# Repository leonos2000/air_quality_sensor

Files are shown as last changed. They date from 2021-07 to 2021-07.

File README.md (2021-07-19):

# Air Quality Sensor

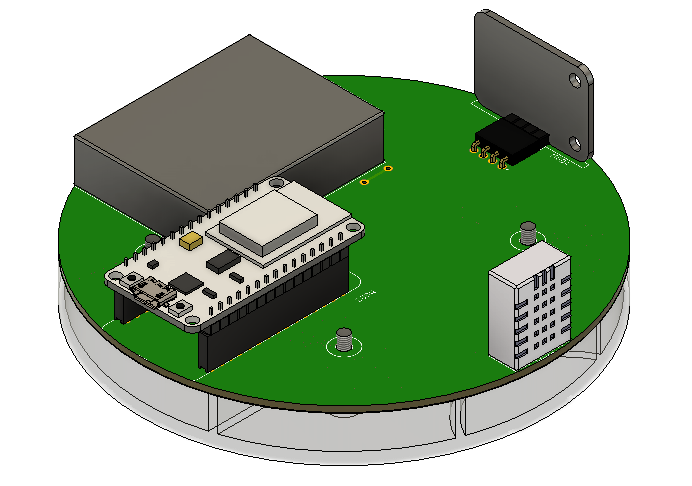
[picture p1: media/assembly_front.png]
3d_assembly

## Overview

This is air quality sensor that can measure PM1.0, PM2.5, PM10, tVOC and eCO2, but also temperature and humidity.

This is second version of my project witch has some improvements for example separators in 3d printed casing that prevent heating DHT22 sensor from nodeMCU.

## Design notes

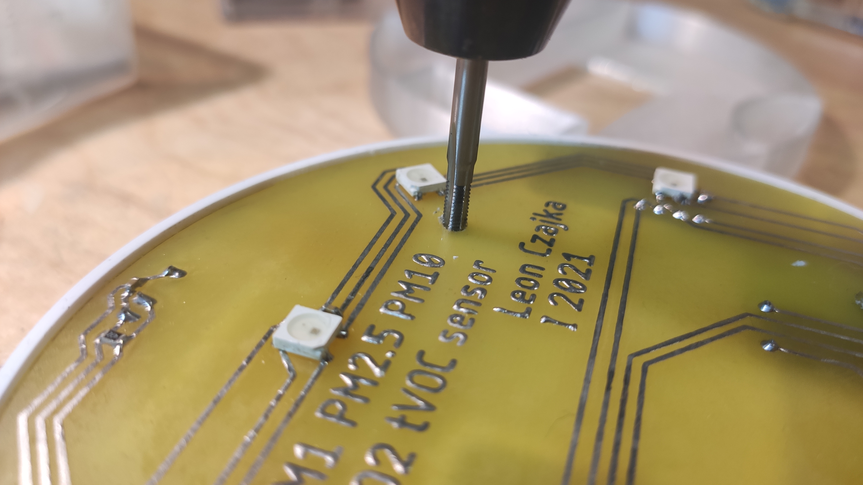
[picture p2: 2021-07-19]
media/tapping.jpg

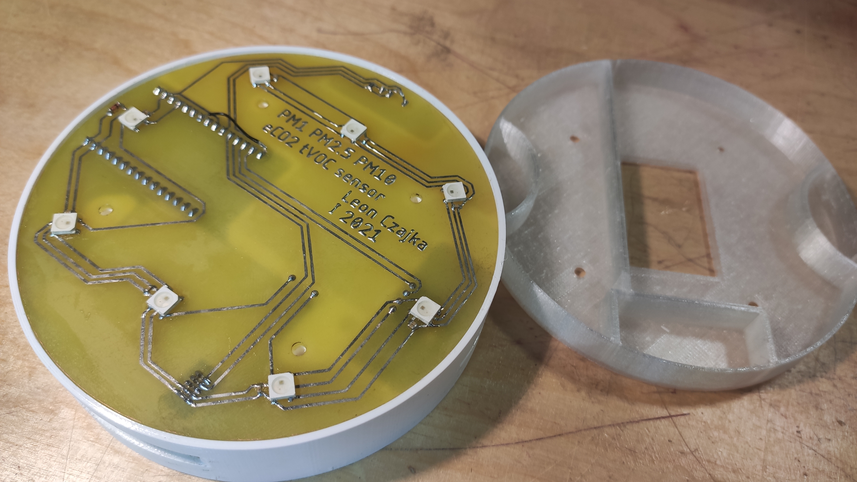
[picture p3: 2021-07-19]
media/pcb_bottom.jpg

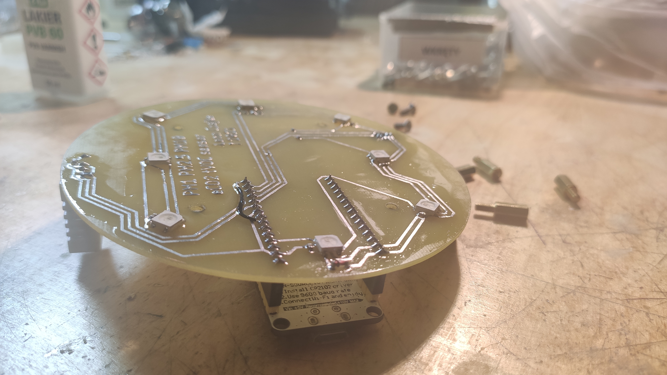
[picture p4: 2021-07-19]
media/pcb.jpg

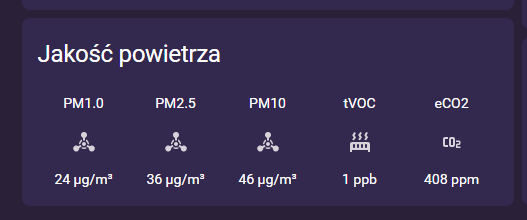
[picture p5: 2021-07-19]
media/home_assistant.png

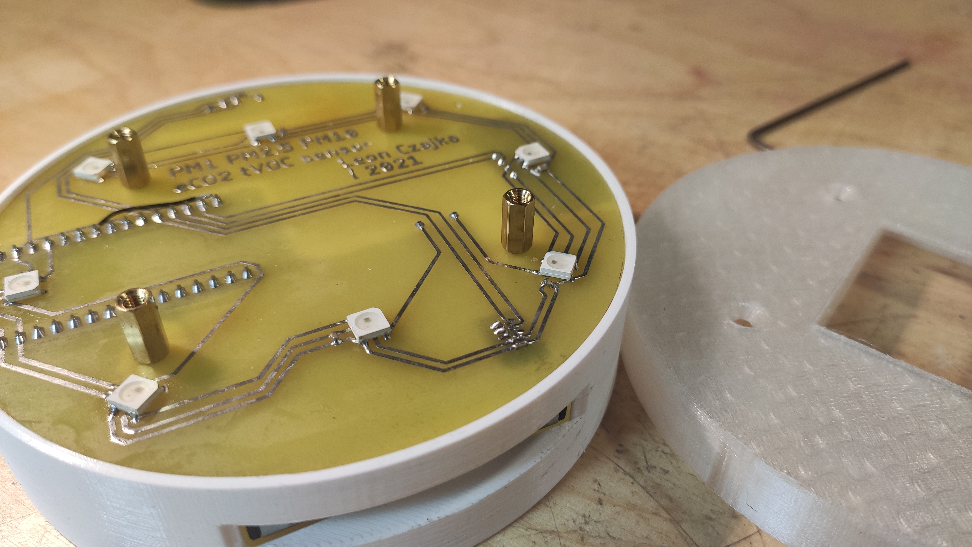
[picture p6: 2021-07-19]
media/pcb_with_spacers.jpg

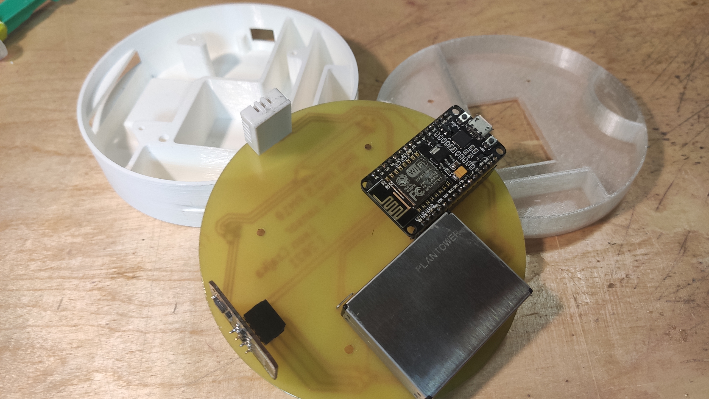
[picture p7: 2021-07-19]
media/all_top.jpg

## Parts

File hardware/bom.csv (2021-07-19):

Part | Value | Device | Package
C1 | 100n | C-EUC0603 | C0603
C2 | 100n | C-EUC0603 | C0603
C3 | 100n | C-EUC0603 | C0603
C4 | 100n | C-EUC0603 | C0603
C5 | 100n | C-EUC0603 | C0603
C6 | 100n | C-EUC0603 | C0603
C7 | 100n | C-EUC0603 | C0603
C8 | 100n | C-EUC0603 | C0603
C9 | 100n | C-EUC0603 | C0603
D1 | 1N4148 | DIODE-MINIMELF | MINIMELF
LED1 | WS2812B | WS2812B | WS2812B
LED2 | WS2812B | WS2812B | WS2812B
LED3 | WS2812B | WS2812B | WS2812B
LED4 | WS2812B | WS2812B | WS2812B
LED5 | WS2812B | WS2812B | WS2812B
LED6 | WS2812B | WS2812B | WS2812B
LED7 | WS2812B | WS2812B | WS2812B
LED8 | WS2812B | WS2812B | WS2812B
MOD1 | PMS7003 | PMS7003 | PMS7003
MOD2 | NODEMCU | NODEMCUWITHOUT-HOLES | NODEMCU-WITHOUT-HOLES
MOD3 | DHT22 | DHT22-3PIN | DHT22_STRAIGHT-3PIN
MOD4 | CCS811 | CCS811_ANGLE | HDRRAR4W64P254_1X4_1016X736X254B
R1 | 4k7 | R-EU_M0805 | M0805
SPACER1 | M3x10mm
SPACER2 | M3x10mm
SPACER3 | M3x10mm
SPACER4 | M3x10mm
BOLT1 | M3x10mm Cone
BOLT2 | M3x10mm Cone
BOLT3 | M3x10mm Cone
BOLT4 | M3x10mm Cone

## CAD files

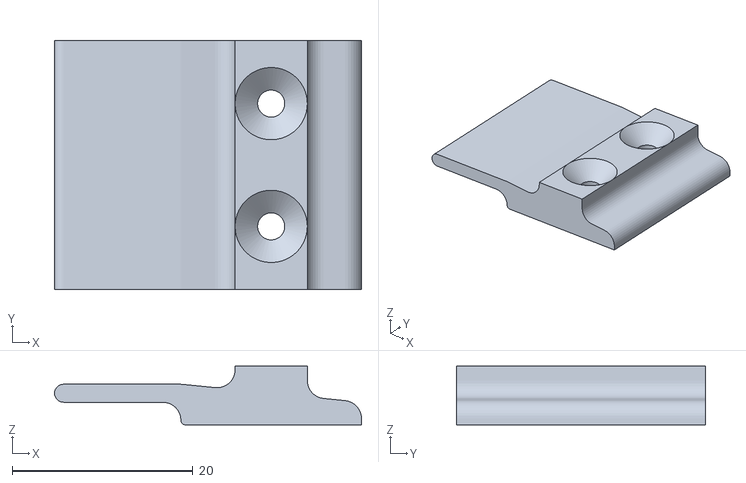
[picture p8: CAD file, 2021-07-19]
3d_models/mounting.stl
34.0 x 27.6 x 6.50

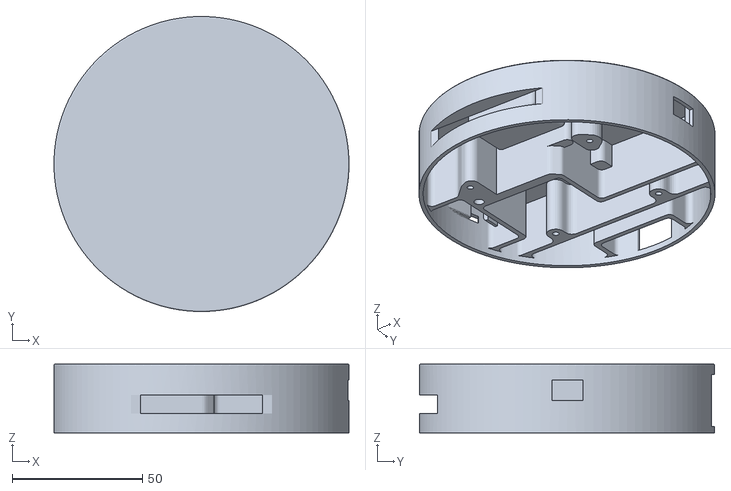
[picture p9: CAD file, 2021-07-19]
3d_models/case-top.stl
113.4 x 113.4 x 26.5

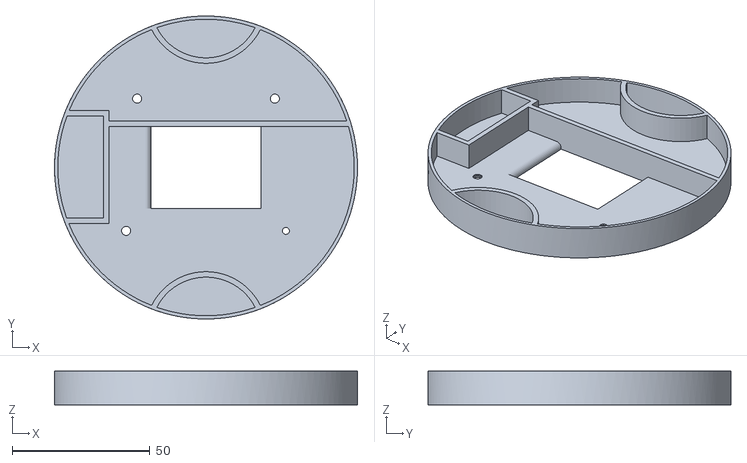
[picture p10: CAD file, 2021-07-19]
3d_models/case-bottom-transparent.stl
110.0 x 110.0 x 12.3

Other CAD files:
3d_models/air_quality_sensor.f3z

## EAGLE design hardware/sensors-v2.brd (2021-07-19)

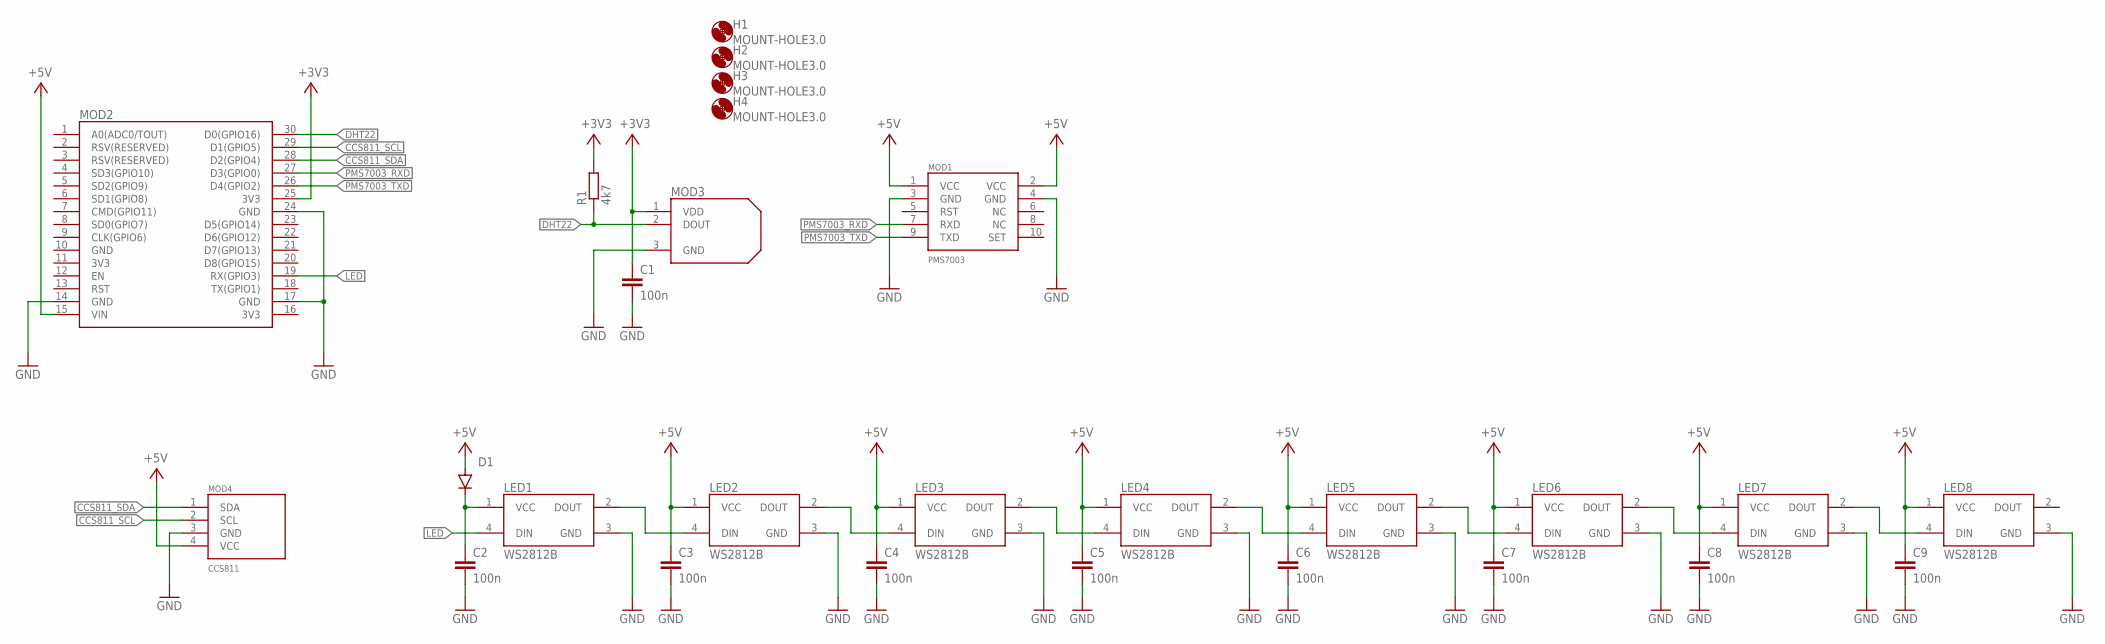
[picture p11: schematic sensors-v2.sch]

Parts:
C1, C2, C3, C4, C5, C6, C7, C8, C9: 100n; C0603
D1: DIODE-MINIMELF; MINIMELF
H1, H2, H3, H4: MOUNT-HOLE3.0; 3,0
LED1, LED2, LED3, LED4, LED5, LED6, LED7, LED8: WS2812B
MOD1: PMS7003
MOD2: NODEMCU; NODEMCU-WITHOUT-HOLES
MOD3: DHT22; DHT22_STRAIGHT-3PIN
MOD4: CCS811; HDRRAR4W64P254_1X4_1016X736X254B
R1: 4k7; M0805

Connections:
+3V3: C1.1, MOD2.25 (3V3), MOD3.1 (VDD), R1.2
+5V: C3.1, C4.1, C5.1, C6.1, C7.1, C8.1, C9.1, D1.A, LED2.1 (VCC), LED3.1 (VCC), LED4.1 (VCC), LED5.1 (VCC), LED6.1 (VCC), LED7.1 (VCC), LED8.1 (VCC), MOD1.1 (VCC), MOD1.2 (VCC), MOD2.15 (VIN), MOD4.4 (VCC)
CCS811_SCL: MOD2.29 (D1(GPIO5)), MOD4.2 (SCL)
CCS811_SDA: MOD2.28 (D2(GPIO4)), MOD4.1 (SDA)
DHT22: MOD2.30 (D0(GPIO16)), MOD3.2 (DOUT), R1.1
GND: C1.2, C2.2, C3.2, C4.2, C5.2, C6.2, C7.2, C8.2, C9.2, LED1.3 (GND), LED2.3 (GND), LED3.3 (GND), LED4.3 (GND), LED5.3 (GND), LED6.3 (GND), LED7.3 (GND), LED8.3 (GND), MOD1.3 (GND), MOD1.4 (GND), MOD2.14 (GND), MOD2.17 (GND), MOD2.24 (GND), MOD3.3 (GND), MOD4.3 (GND)
LED: LED1.4 (DIN), MOD2.19 (RX(GPIO3))
unnamed: C2.1, D1.C, LED1.1 (VCC)
unnamed: LED2.2 (DOUT), LED3.4 (DIN)
unnamed: LED3.2 (DOUT), LED4.4 (DIN)
unnamed: LED1.2 (DOUT), LED2.4 (DIN)
unnamed: LED4.2 (DOUT), LED5.4 (DIN)
unnamed: LED5.2 (DOUT), LED6.4 (DIN)
unnamed: LED6.2 (DOUT), LED7.4 (DIN)
unnamed: LED7.2 (DOUT), LED8.4 (DIN)
PMS7003_RXD: MOD1.7 (RXD), MOD2.27 (D3(GPIO0))
PMS7003_TXD: MOD1.9 (TXD), MOD2.26 (D4(GPIO2))

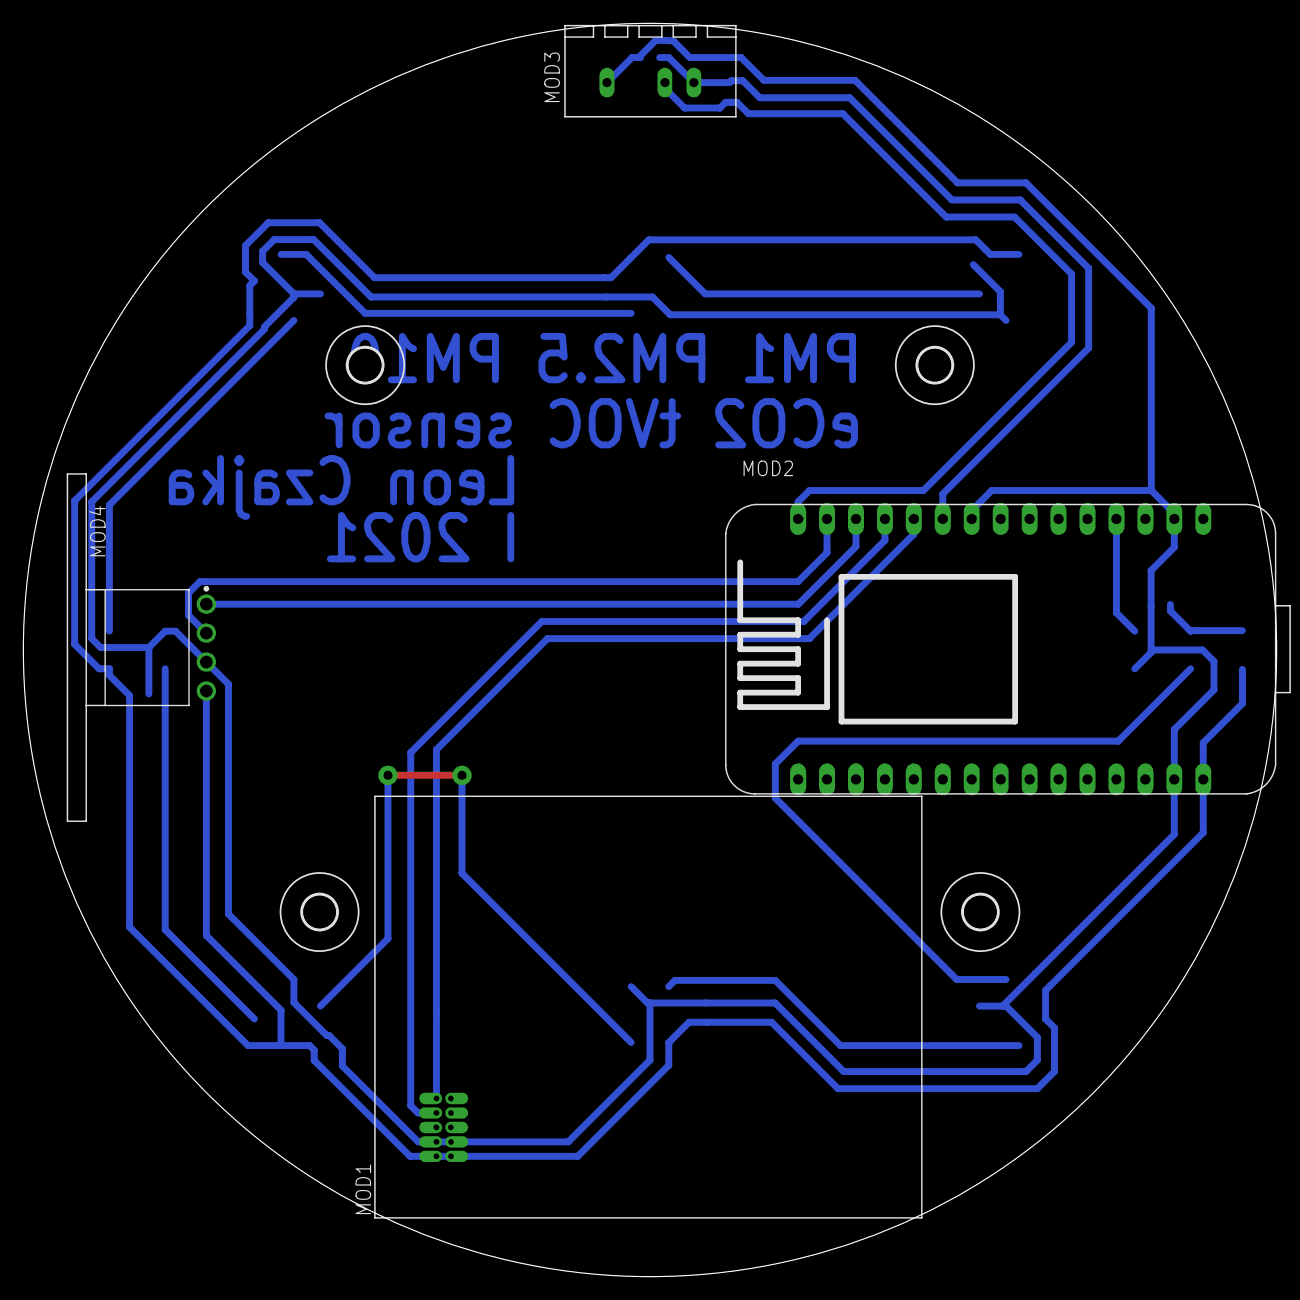
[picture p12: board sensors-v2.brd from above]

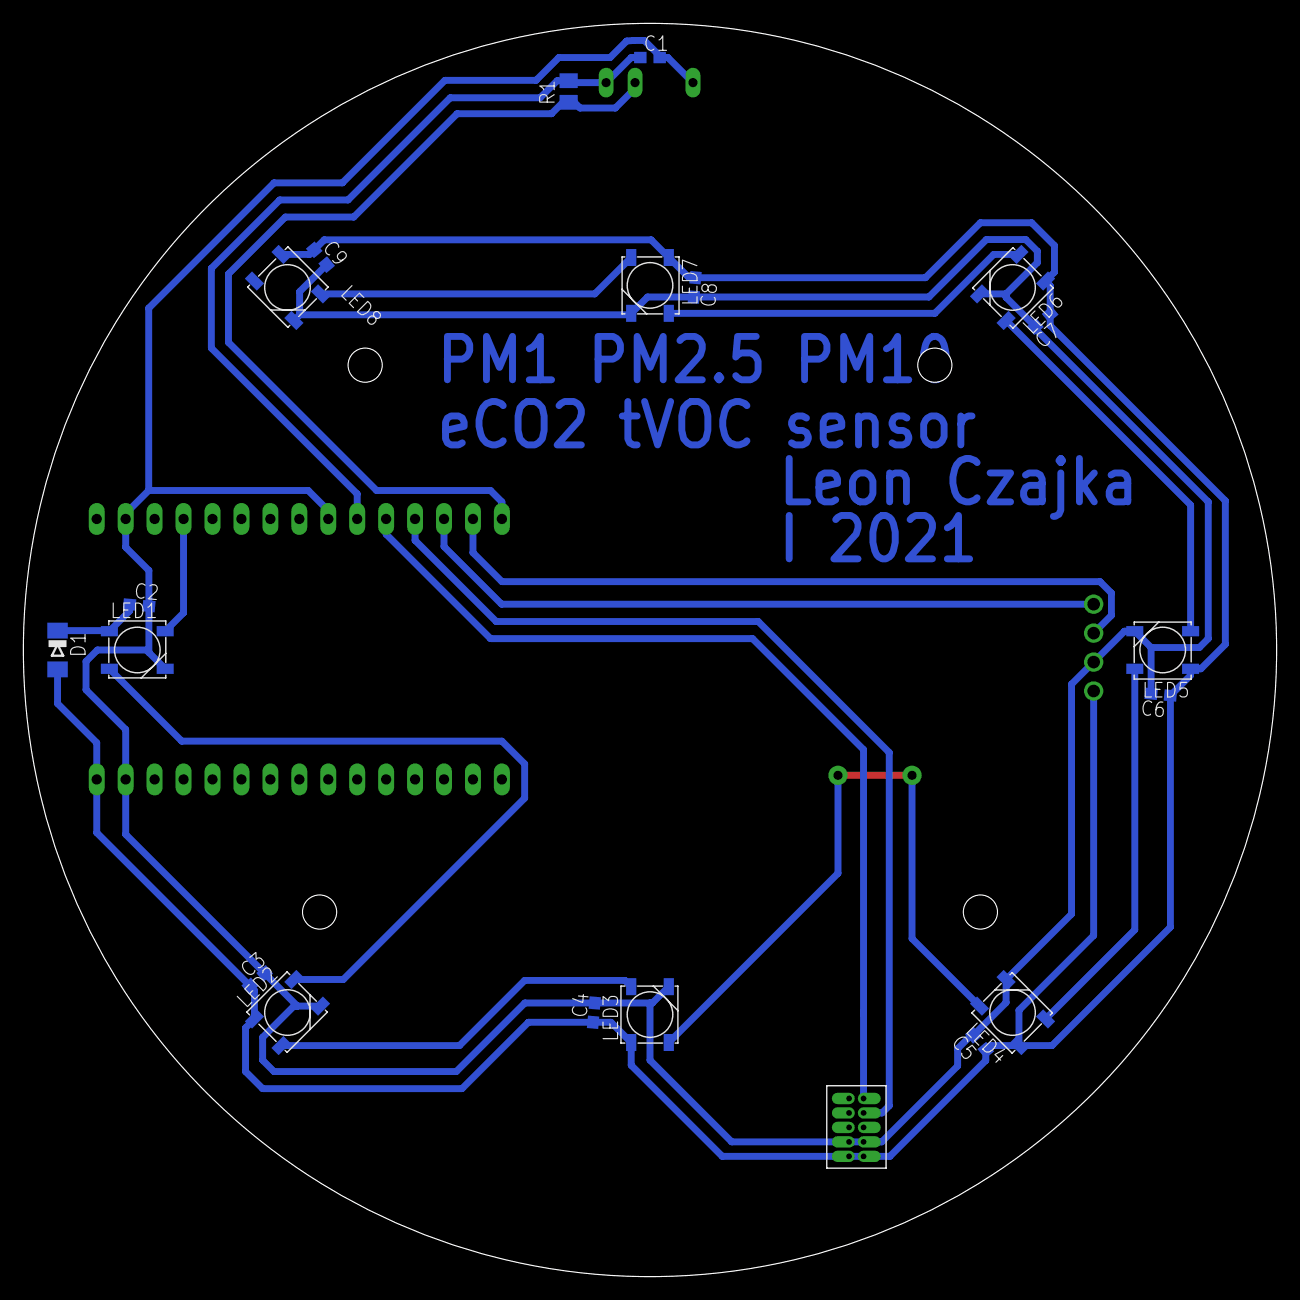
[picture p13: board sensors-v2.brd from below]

Board: 2 copper layers, 110.0 x 110.0 mm, 27 parts (19 on the bottom side), 17 nets.
